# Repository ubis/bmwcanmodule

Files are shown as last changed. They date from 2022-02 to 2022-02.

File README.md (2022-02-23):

# BMW CAN Module

Just really simple CAN BUS device based on PIC18LF26K80 to emulate PDC/HDC/CAM commands.

BMW F Series cars up to 2011-06 (I think) had I-Drive (ZBE) controllers with 10-pin plugs. After 2011-07 BMW started to use controllers with 4-pin plugs.

ZBE communicates through CAN BUS (K-CAN) using 2 wires and it needs 2 wires for power. Then 1 wire (ADC) is used for PDC/HDC/CAM buttons and 1 or 2 wires for PDC and/or HDC LED lights. Which means that 10-pin ZBE also sends messages to K-CAN when PDC/HDC/CAM button is pressed and lights up appropriate LED light.

Once you plug-in 4-pin K-CAN ZBE, you will no longer have these buttons working nor LED lights. For this purpose I made a really simple emulator - to read ADC keys and send messages once pressed, and of course, control PDC/HDC "active" LED lights.

**Note: At the moment only PDC functionality is supported. I do not have CAN frames for HDC/CAM control, yet.**

# CAN BUS, K-CAN, K-CAN2, ...

BMW just calls CAN BUS `K-CAN`, that is pretty much it. Now K-CAN runs at 100Kbps speed while K-CAN2 and others, K-CAN3/K-CAN4 runs at 500Kbps.

# Hardware

I needed low-powered MCU with CAN peripheral. I am quite familiar with Atmel AVR MCU devices as well as with STMicroelectronics STM32F10x devices.

However, Atmel does not seem to have AVR with CAN peripheral and something like STM32F103 would be really overkill for such a simple device. Also initially I thought that PDC/HDC LED lights are powered by 5V (12V actually) so I thought there is no point to use 3.3V MCU - I will need 12V -> 3.3V and 12V -> 5.0V voltage converters.

Then I looked into Microchip PIC devices and found PIC18LF26K80 in stock. I have not used any PIC device before at all, so it was my first time programming it and using Microchip's IDE.

For 12V -> 5.0V converter I have used MCP170 and for CAN transceiver - MCP2551. A few NPN and PNP transistors (S8050, S8550) to control PDC/HDC LED outputs. I have also added CAN ESD protection diode called PESD2CAN, just in case.

# Firmware

I have used MPLAB IDE and PicKit 3.

It reads button states by reading ADC value periodically. Once key is released, PIC will send  a message through K-CAN to let others (CIC, etc) know that PDC should be turned on.

When PDC is turned on (via reverse gear or message from PIC) some car other module will transmit message that PDC is really active. PIC will listen for that message too, to control PDC LED output.

And of course, I have enabled sleep mode. PIC will wake up on CAN activity and will listen for "terminal on" message for about 5 seconds before going to sleep again. Once such message is received, it will continue to stay awake until "terminal off" command is received, then PIC will enter sleep mode again.

# Power consumption, sleep mode

I measured 0.035mA current consumption in sleep mode. Keep in mind, this is MCP170 + MCP2551 CAN transceiver in stand-by mode and PIC itself. For comparison, 10-pin ZBE uses about 1.45mA in sleep mode.

If PIC is not sleeping then it will use about 12.5mA, this is without LED outputs, and ZBE seem to use 85.5mA current.

# Wiring

I have used 4-pin connectors `BMW 1452576` (1 male and 2 females) and this made it to be Plug'n'Play. You can find these in eBay, AliExpress, etc.

This is the wiring for 4-pin ZBE:

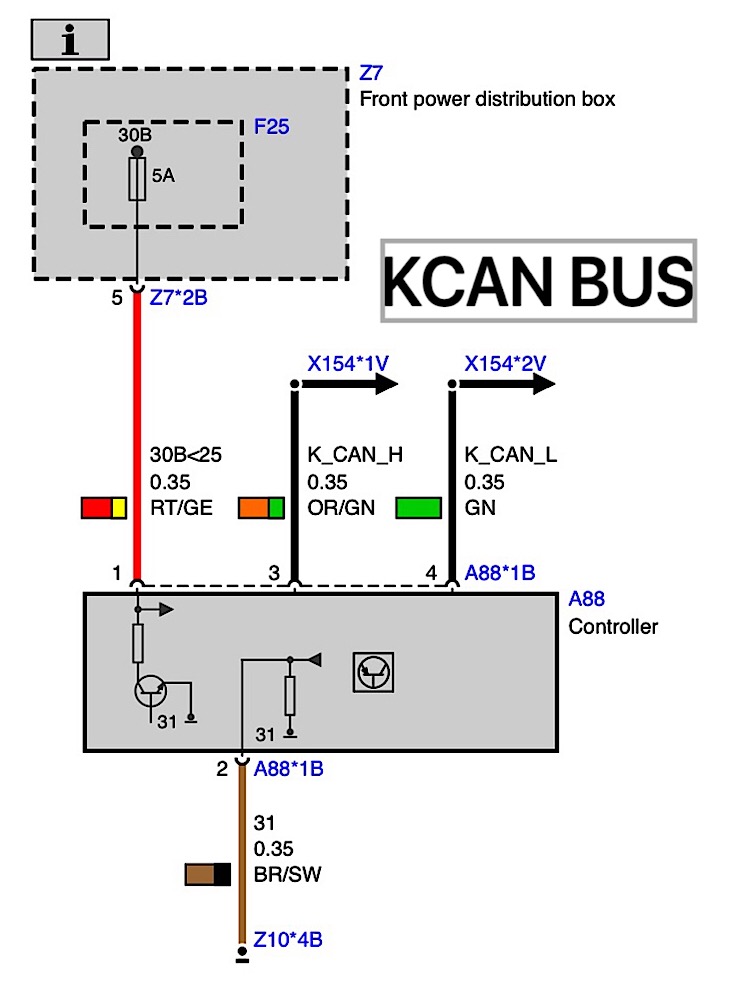
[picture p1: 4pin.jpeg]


And this is for 10-pin ZBE:

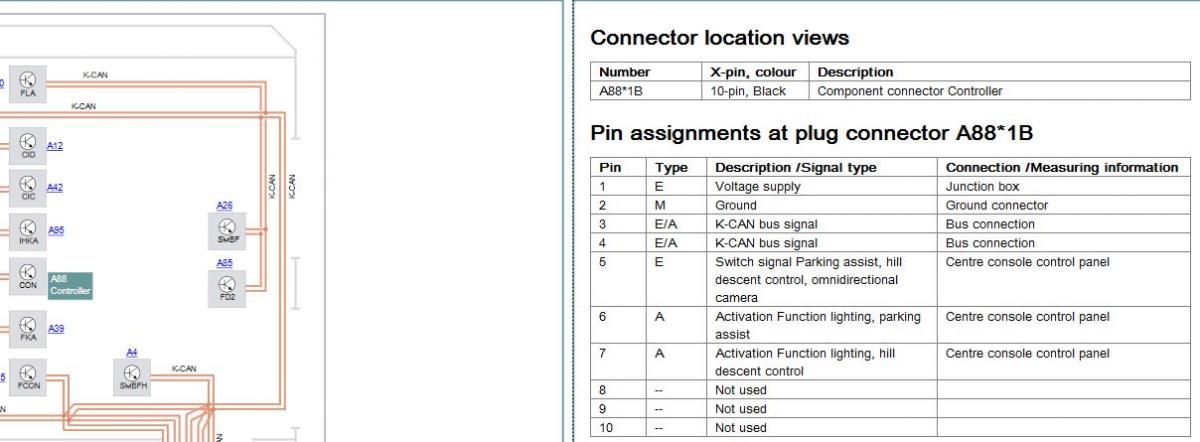
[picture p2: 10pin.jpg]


Note: 3-pin is CAN_HIGH and 4-pin is CAN_LOW on both variants.

As you can see you can use 4-pin ZBE instead of 10-pin, but you will loose functionality of PDC/HDC/CAM buttons and LED outputs.

# Rest

I am publishing everything what is needed to build such a device - schematics, firmware source and enclosure to 3D print. I have used EasyEDA to draw schematic and PCB, look up in `hardware` directory.

I might work on v2 version where will be 2 CAN peripherals, one is at 100Kbps and other is at 500Kbps. The latter would allow to use even newer ZBE controllers since they use K-CAN2 in NBT infotainment system and you cannot just connect K-CAN to K-CAN2/3/4, it will simply would not work due to different speeds.

In the following pictures you can see first version of the board where I made some mistakes and fixed them using Kynar wires. I am publishing updated v1.1 schematic and PCB where those mistakes should be fixed.

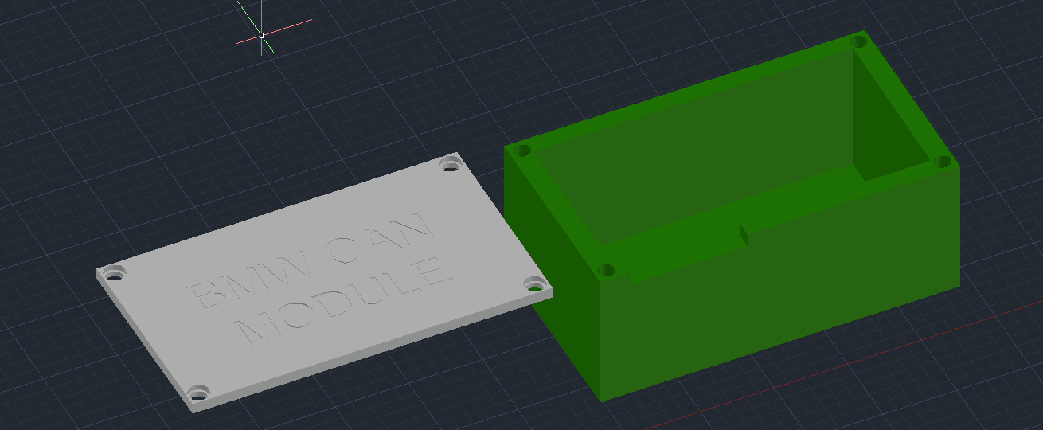
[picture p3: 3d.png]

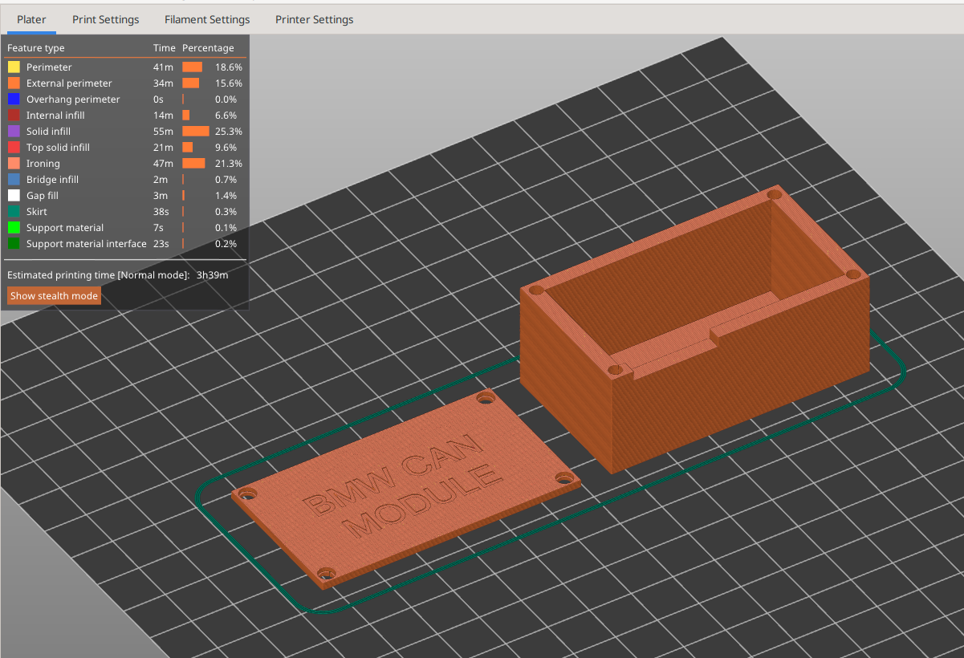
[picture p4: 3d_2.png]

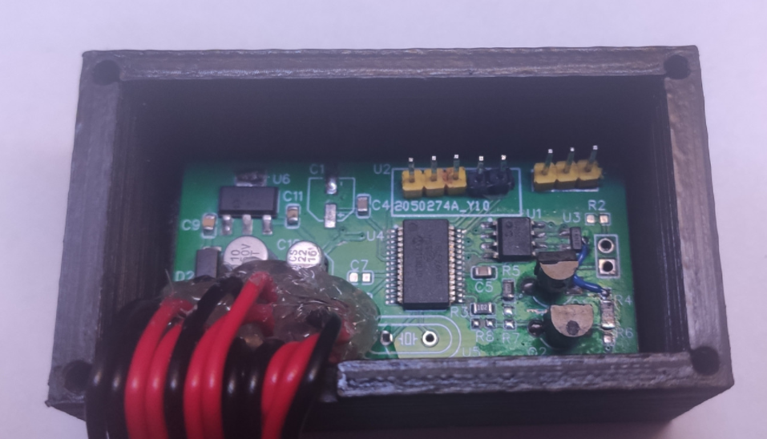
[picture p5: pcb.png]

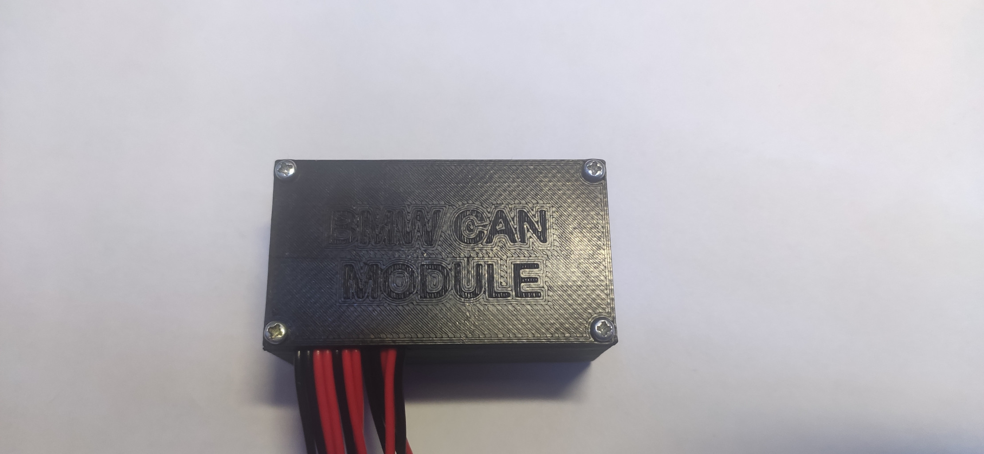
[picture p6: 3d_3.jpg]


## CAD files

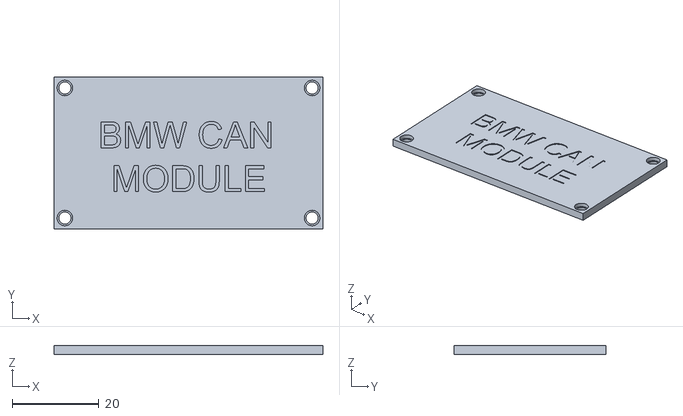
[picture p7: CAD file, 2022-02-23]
3d/bmwcanmodule3d-top.stl
62.0 x 35.0 x 2.00

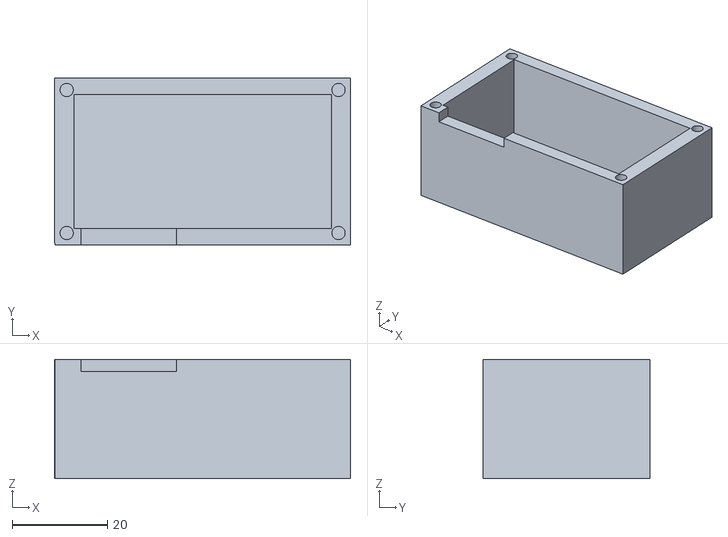
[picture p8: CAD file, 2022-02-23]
3d/bmwcanmodule3d-bottom.stl
62.1 x 35.0 x 25.0

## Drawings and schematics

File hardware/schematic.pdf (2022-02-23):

### CAN_RX

### CAN_TX

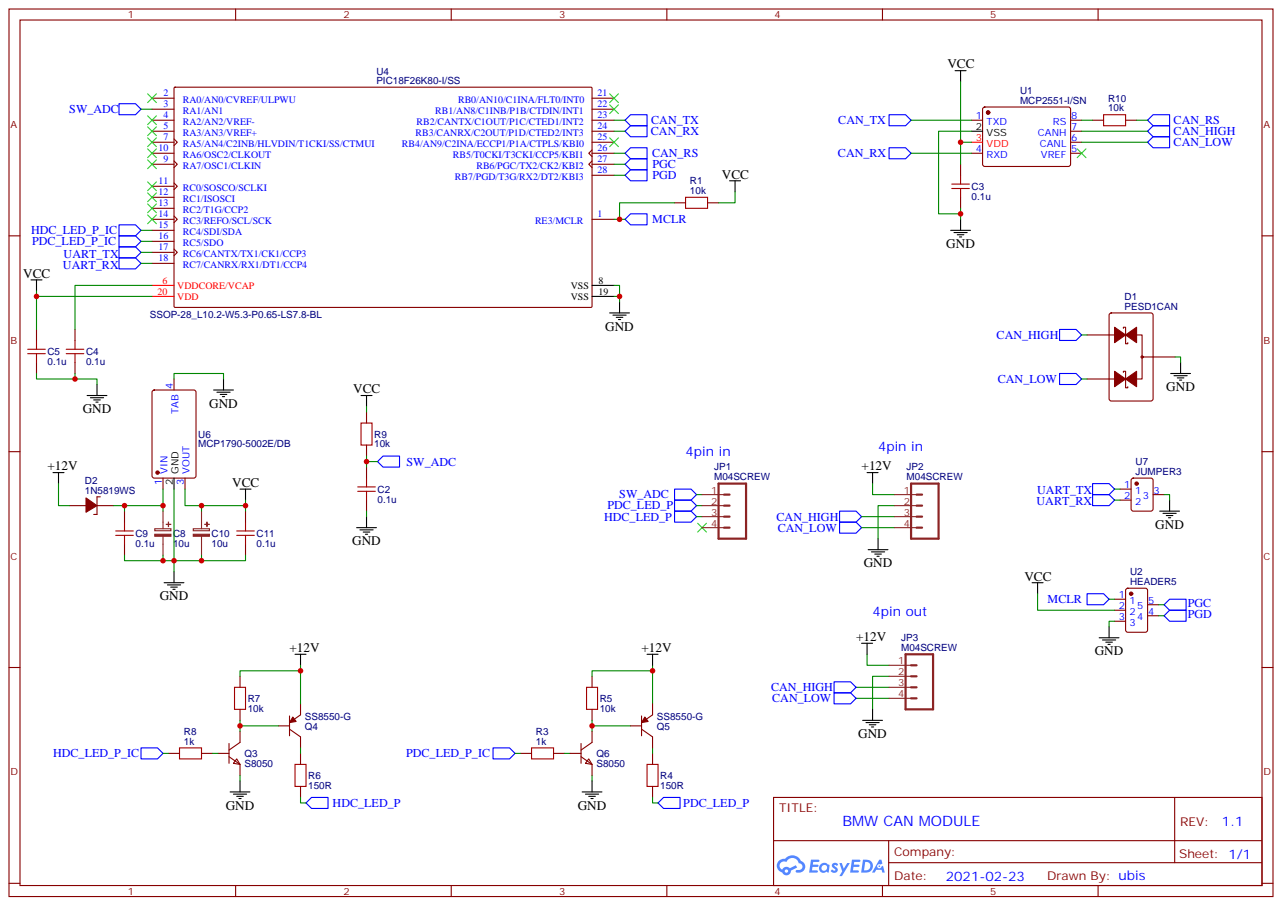
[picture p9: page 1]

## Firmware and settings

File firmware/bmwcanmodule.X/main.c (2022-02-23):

#include "mcc_generated_files/mcc.h"
#include <string.h>
#include "cmd.h"
#include "conf.h"
#include "version.h"

#ifndef ARRAY_SIZE
#define ARRAY_SIZE(arr) sizeof(arr) / sizeof(arr[0])
#endif // ARRAY_SIZE

enum btn_id {
    BTN_PDC,
    BTN_HDC,
    BTN_CAM,
};

typedef struct {
    int min;
    int max;
    char *label;
    bool pressed;
} btn_info_t;

static volatile bool g_CanRxMsg;
static volatile bool g_ADCDone;
static volatile uint64_t g_Millis;
static uint64_t g_SleepCnt;
static bool g_WakeFlag;

static btn_info_t g_btn[] = {
    [BTN_PDC] = { PDC_ADC_MIN_VALUE, PDC_ADC_MAX_VALUE, "PDC", false },
    [BTN_HDC] = { HDC_ADC_MIN_VALUE, HDC_ADC_MAX_VALUE, "HDC", false },
    [BTN_CAM] = { CAM_ADC_MIN_VALUE, CAM_ADC_MAX_VALUE, "CAM", false },
};

static void CanRxIRQHandler(void) {
    g_CanRxMsg = true;
}

static void Timer0IRQHandler(void) {
    g_Millis++;
}

static void ADCIRQHandler(void) {
    g_ADCDone = true;
}

static void CanFilterSetupId(int type) {
    printf("CAN ");

    if (type == dSTANDARD_CAN_MSG_ID_2_0B) {
        RXF0SIDL &= ~(1 << 3);
        printf("standard");
    } else if (type == dEXTENDED_CAN_MSG_ID_2_0B) {
        RXF0SIDL |= (1 << 3);
        printf("extended");
    }
    
    printf(" ID messages enabled\r\n");
}

static void IsWakeCommand(uCAN_MSG *msg) {
    uint32_t id = msg->frame.id;
    uint8_t len = msg->frame.dlc;
    
    if (id != CMD_WAKE_MESSAGE_ID) {
        return;
    }
    
    if (!len) {
        return;
    }
    
    // wake  0x45 or 0x05
    // sleep 0x40 or 0x00   
    uint8_t cmd = msg->frame.data0 & CMD_WAKE_MESSAGE_MASK;
    g_WakeFlag = (cmd == CMD_WAKE_MESSAGE_ON);
}

static void IsPDCCommand(uCAN_MSG *msg) {
    uint32_t id = msg->frame.id;
    uint8_t len = msg->frame.dlc;
    
    if (id != CMD_PDC_EVT_MESSAGE_ID) {
        return;
    }
    
    if (!len) {
        return;
    }
     
    uint8_t cmd = msg->frame.data0;
    
    if (cmd == CMD_PDC_EVT_MESSAGE_ON) {
        // turn on PDC led output
        PDC_LED_PIN = 1;
    } else if (cmd == CMD_PDC_EVT_MESSAGE_OFF) {
        // turn off PDC led output
        PDC_LED_PIN = 0;
    }
}

static void CanHandleRxMessage(void) {
    uCAN_MSG msg = { 0 };

    if (!g_CanRxMsg) {
        return;
    }
    
    g_CanRxMsg = false;
    
    if (!CAN_receive(&msg)) {
        return;
    }
    
    uint32_t id    = msg.frame.id;
    uint8_t idtype = msg.array[0];
    uint8_t len    = msg.array[5];

#ifdef DEBUG_MODE
    printf("CAN message received: 0x%08lX; ", id);
    printf("identifier: %s; ", idtype == 1 ? "standard" : "extended");
    printf("length: %u; ", len);
    printf("data: ");
               
    for (int i = 6; i < 6 + len; i++) {
        printf("%02X", msg.array[i]);
        
        if ((i + 1) < (6 + len)) {
            printf(" ");
        }
    }
    
    printf("\r\n");
#endif // DEBUG_MODE
    
    IsWakeCommand(&msg);
    IsPDCCommand(&msg);
}

static void SendPDCButtonState(bool state) {
    uCAN_MSG msg = { 0 };
    
    msg.frame.id     = CMD_PDC_BTN_MESSAGE_ID;
    msg.frame.idType = dSTANDARD_CAN_MSG_ID_2_0B;
    msg.frame.dlc    = 2;
    msg.frame.data0  = (state) ? CMD_PDC_BTN_MESSAGE_PRESS : CMD_PDC_BTN_EMSSAGE_RELEASE;
    msg.frame.data1  = 0xFF;
       
    CAN_transmit(&msg);
    
    printf("Sent PDC event button [%02X] message\r\n", msg.frame.data0);
}

void ReadButtonState(void) {
    if (!g_ADCDone) {
        return;
    }
    
    g_ADCDone = false;
    ADC_StartConversion(BTN_ADC_CHANNEL);
    
    uint16_t value = ADC_GetConversionResult();
    
    for (int i = 0; i < ARRAY_SIZE(g_btn); i++) {
        if (!(value >= g_btn[i].min && value <= g_btn[i].max)) {
            continue;
        }

        printf("Received ADC value: %u\r\n", value);
            
        if (g_btn[i].pressed) {
            // already pressed, holding...
            return;
        }
            
        g_btn[i].pressed = true;
        printf("%s button was pressed!\r\n", g_btn[i].label);
            
        if (i == BTN_PDC) {
            SendPDCButtonState(g_btn[i].pressed);
        }
            
        // only single buton press should be available
        return;
    }
    
    for (int i = 0; i < ARRAY_SIZE(g_btn); i++) {
        if (!g_btn[i].pressed) {
            continue;
        }
        
        g_btn[i].pressed = false;
        
        printf("Received ADC value: %u\r\n", value);
        printf("%s button was released!\r\n", g_btn[i].label);
        
        if (i == BTN_PDC) {
            SendPDCButtonState(g_btn[i].pressed);
        }
        
        // only single buton press should be available
        return;
    }
}

static void EnterSleepMode(void) {
    printf("Entering sleep mode...\r\n");
    
    // turn off LED outputs
    HDC_LED_PIN = 0;
    PDC_LED_PIN = 0; 
    
    // put CAN transceiver into stand-by mode (RS->HIGH)
    CAN_RS_PIN = 1;
    
    // put CAN into sleep mode
    CAN_sleep();

     // enter sleep mode on Sleep()
    OSCCONbits.IDLEN = 0;
    
    Sleep();

    NOP();

    printf("Wake up\r\n");

    // put CAN transceiver into high-speed mode (RS->LOW)
    CAN_RS_PIN = 0;
}

void main(void) {
    SYSTEM_Initialize();
    
    printf("\r\n");
    printf("BMW CAN Module v%d.%d ", FW_VERSION_MAJOR, FW_VERSION_MINOR);
    printf("(build: %s - %s)\r\n", __TIME__, __DATE__);
    
    // configure CAN-RS PDC & HDC led pins as outputs
    CAN_RS_PIN_PORT &= ~(CAN_RS_PIN_BIT);
    PDC_LED_PIN_PORT &= ~(PDC_LED_PIN_BIT);
    HDC_LED_PIN_PORT &= ~(HDC_LED_PIN_BIT);
    
    // put CAN transceiver into high-speed mode (RS->LOW)
    CAN_RS_PIN = 0;
    
    // turn off LED outputs
    HDC_LED_PIN = 0;
    PDC_LED_PIN = 0; 

    INTERRUPT_GlobalInterruptEnable();
    INTERRUPT_PeripheralInterruptEnable();
    
    ECAN_SetRXB0InterruptHandler(CanRxIRQHandler);
    ECAN_SetRXB1InterruptHandler(CanRxIRQHandler);
    TMR0_SetInterruptHandler(Timer0IRQHandler);
    ADC_SetInterruptHandler(ADCIRQHandler);
    
    TMR0_StartTimer();
    
    // configure CAN to accept standard or extended messages
    //CanFilterSetupId(dEXTENDED_CAN_MSG_ID_2_0B);
    CanFilterSetupId(dSTANDARD_CAN_MSG_ID_2_0B);
    
    // disable CAN message filters
    //RXB0CONbits.RXM0 = 1;
    //RXB0CONbits.RXM1 = 1;
    
    // start ADC conversion
    ADC_StartConversion(BTN_ADC_CHANNEL);
            
#ifdef DEBUG_MODE
    uint64_t prev = 0;
#endif // DEBUG_MODE
        
    while (1) {
        CanHandleRxMessage();
        ReadButtonState();

        uint64_t now = g_Millis;

#ifdef DEBUG_MODE
        if (now - prev >= 500) {
            printf("Alive\r\n");
            prev = now;
        }
#endif // DEBUG_MODE

        if (!g_WakeFlag && now - g_SleepCnt >= 5000) {
            g_SleepCnt = now;

            printf("No Keep-Alive message received\r\n");
            EnterSleepMode();
        }
    }
}

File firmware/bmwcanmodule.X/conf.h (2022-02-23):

/* 
 * File:   conf.h  
 * Author: Jokubas Maciulaitis (ubis)
 * Date:   2022 02 16 
 */

#ifndef __CONF_H__
#define	__CONF_H__

#define DEBUG_MODE

// CAN RS pin configuration
#define CAN_RS_PIN        RB5
#define CAN_RS_PIN_BIT    (1 << 5)
#define CAN_RS_PIN_PORT   TRISB

// PDC/HDC led output configuration
#define HDC_LED_PIN       RC4
#define HDC_LED_PIN_BIT   (1 << 4)
#define HDC_LED_PIN_PORT  TRISC

#define PDC_LED_PIN       RC5
#define PDC_LED_PIN_BIT   (1 << 5)
#define PDC_LED_PIN_PORT  TRISC

// ADC input button configuration
#define BTN_ADC_CHANNEL   1

// ADC button values
#define PDC_ADC_MIN_VALUE 1000
#define PDC_ADC_MAX_VALUE 4000

#define HDC_ADC_MIN_VALUE 5000
#define HDC_ADC_MAX_VALUE 10000

#define CAM_ADC_MIN_VALUE 11000
#define CAM_ADC_MAX_VALUE 18000

#endif	// __CONF_H__
